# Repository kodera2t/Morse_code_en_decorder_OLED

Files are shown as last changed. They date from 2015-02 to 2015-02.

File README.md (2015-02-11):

# Morse_code_en_decorder_OLED
Morse code en decorder based on Arduino with OLED SPI display. Word per minutes is adjustable by rotary-encorder.
As a by-product project to my Tiny computer project, I made an stand-alone Tiny Morse code encoder/decorder. 
The procedure to make and program is almost same as previous one, 
http://hackaday.io/project/4201-really-tiny-computer-for-basic-bitlash-and-morse 
but the hardware is not same any more.

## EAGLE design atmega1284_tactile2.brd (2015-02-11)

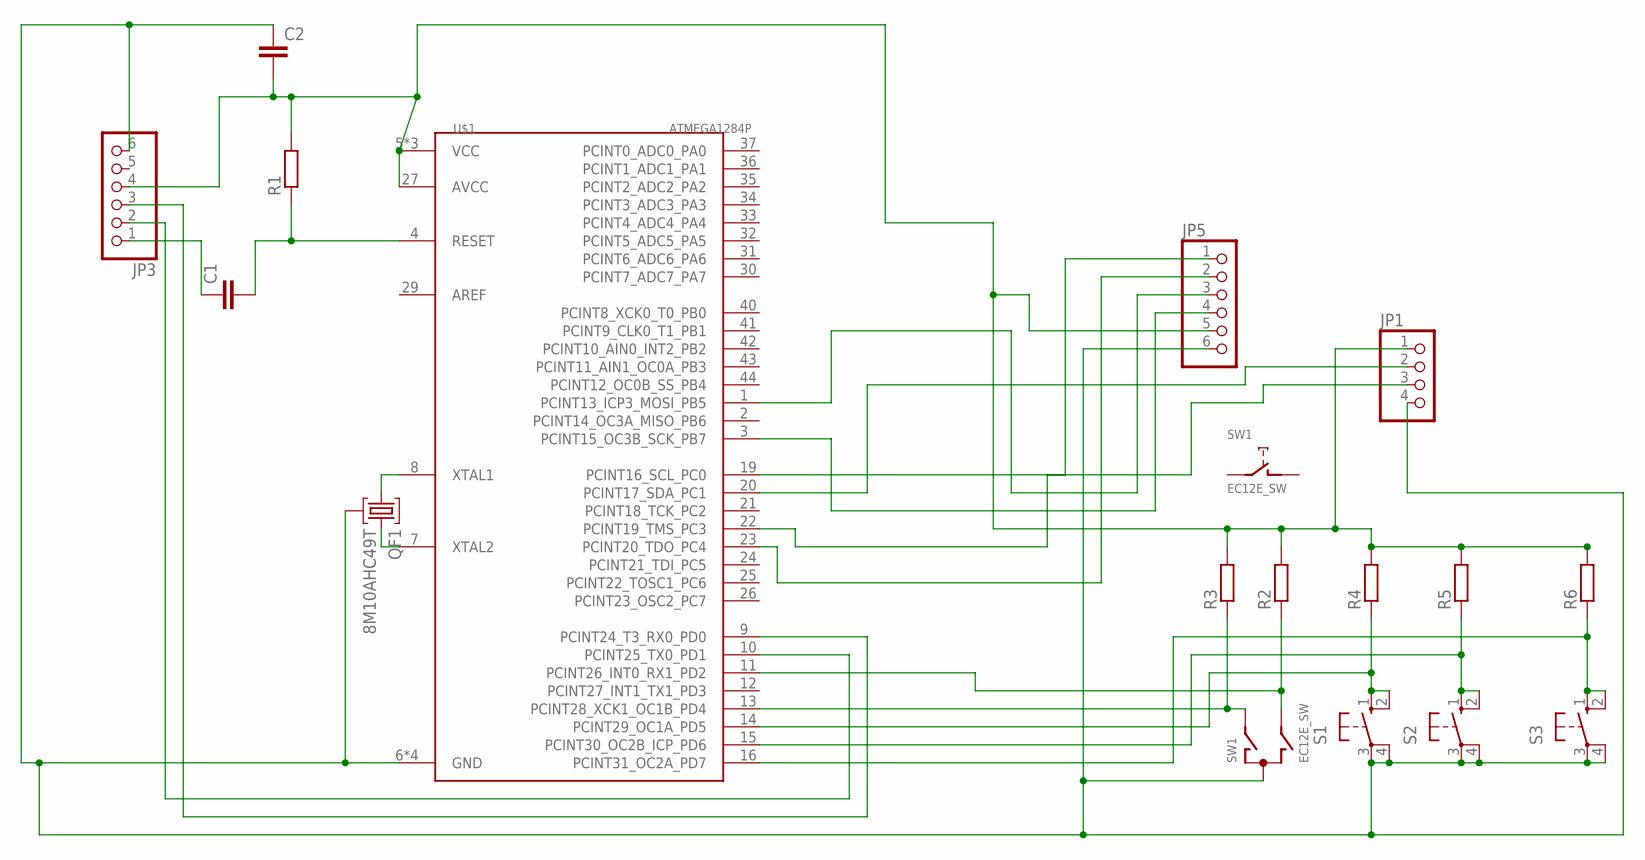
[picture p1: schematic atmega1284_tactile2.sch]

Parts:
C1, C2: C-EUC0805; C0805
JP1: PINHD-1X4; 1X04
JP3, JP5: PINHD-1X6; 1X06
QF1: 8M10AHC49T; HC49U
R1, R2, R3, R4, R5, R6: R-EU_R0805; R0805
S1, S2, S3: 10-XX; B3F-10XX
SW1: EC12E_SW; ALPS_EC12E_SW
U$1: ATMEGA1284P; TQFP44

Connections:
unnamed: JP5.3, U$1.1 (PCINT13_ICP3_MOSI_PB5)
unnamed: QF1.1, U$1.8 (XTAL1)
unnamed: QF1.3, U$1.7 (XTAL2)
unnamed: C2.1, JP1.4, JP3.6, JP5.6, QF1.2, S1.3, S1.4 (P1), S2.3, S2.4 (P1), S3.3, S3.4 (P1), SW1.C, U$1.6 (GND), U$1.18 (GND), U$1.28 (GND), U$1.39 (GND)
unnamed: JP5.4, U$1.3 (PCINT15_OC3B_SCK_PB7)
unnamed: R2.1, SW1.B, U$1.11 (PCINT26_INT0_RX1_PD2)
unnamed: C1.2, R1.1, U$1.4 (RESET)
unnamed: C1.1, JP3.1
unnamed: JP3.2, U$1.10 (PCINT25_TX0_PD1)
unnamed: JP3.3, U$1.9 (PCINT24_T3_RX0_PD0)
unnamed: JP5.1, U$1.22 (PCINT19_TMS_PC3)
unnamed: JP5.2, U$1.23 (PCINT20_TDO_PC4)
unnamed: R3.1, SW1.A, U$1.13 (PCINT28_XCK1_OC1B_PD4)
unnamed: R4.1, S1.1 (S), S1.2 (S1), U$1.14 (PCINT29_OC1A_PD5)
unnamed: R5.1, S2.1 (S), S2.2 (S1), U$1.15 (PCINT30_OC2B_ICP_PD6)
unnamed: R6.1, S3.1 (S), S3.2 (S1), U$1.16 (PCINT31_OC2A_PD7)
unnamed: C2.2, JP1.1, JP3.4, JP5.5, R1.2, R2.2, R3.2, R4.2, R5.2, R6.2, U$1.5 (VCC), U$1.17 (VCC), U$1.27 (AVCC), U$1.38 (VCC)
unnamed: JP1.2, U$1.20 (PCINT17_SDA_PC1)
unnamed: JP1.3, U$1.19 (PCINT16_SCL_PC0)

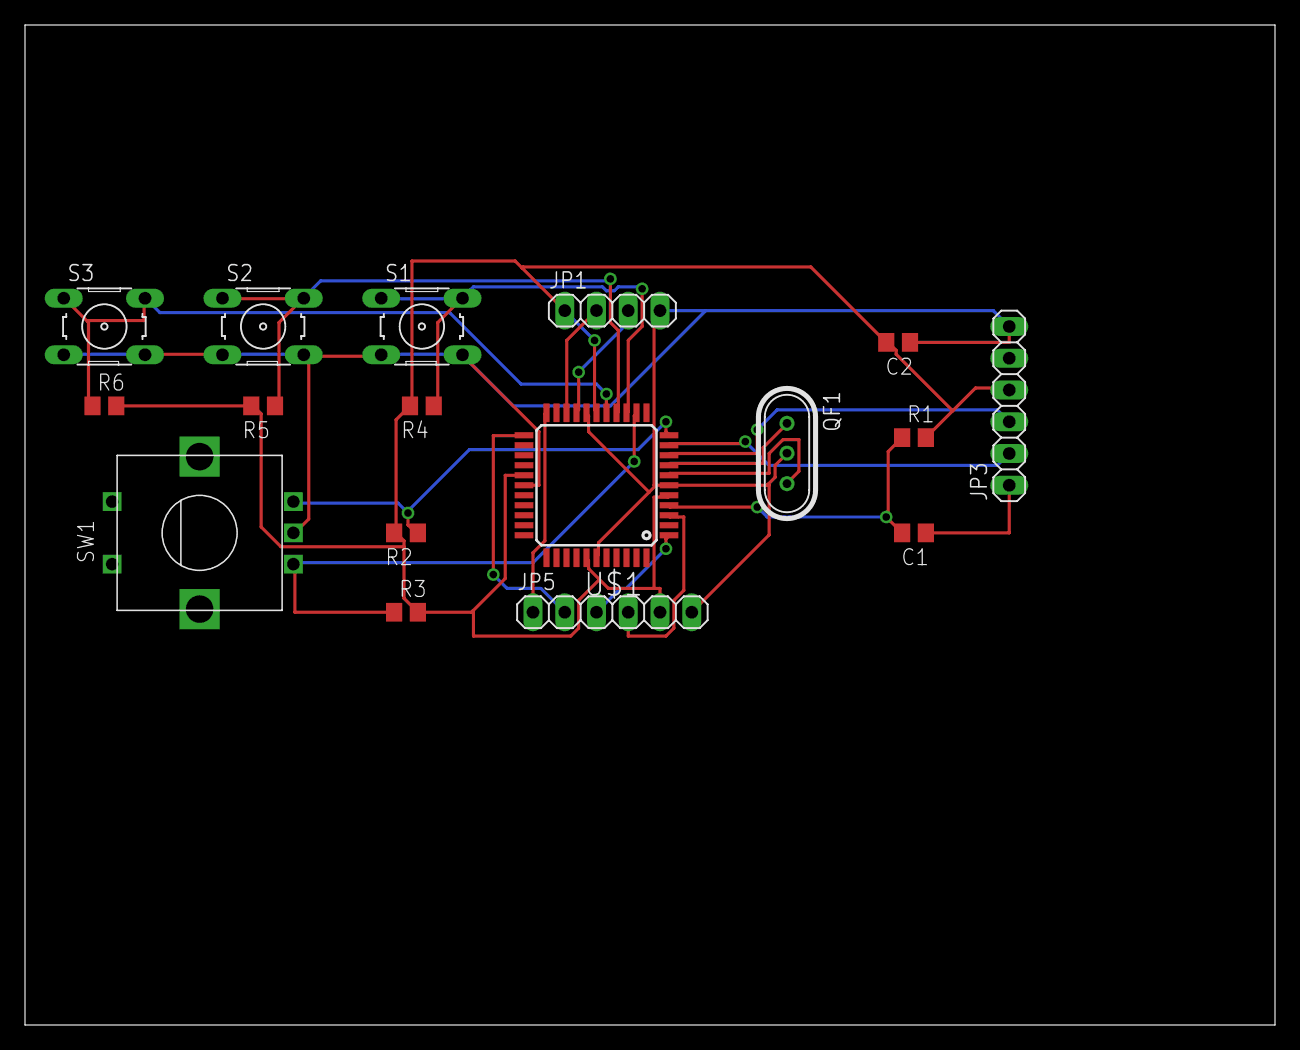
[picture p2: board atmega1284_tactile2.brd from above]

Board: 2 copper layers, 100.0 x 80.0 mm, 17 parts (0 on the bottom side), 19 nets.

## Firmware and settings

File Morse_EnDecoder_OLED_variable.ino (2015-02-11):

#include <avr/pgmspace.h>
#include <MorseEnDecoder.h>


//////////////// Newly added for graphic OLED(LCD) 128x64 support/////////////
#include <SPI.h>
#include <Wire.h>
#include <Adafruit_GFX.h>
#include <Adafruit_SSD1306.h>

// SPI PIN definition. Change to fit your board....
#define OLED_MOSI   5
#define OLED_CLK   7
#define OLED_DC    19
#define OLED_CS    18
#define OLED_RESET 20
Adafruit_SSD1306 display(OLED_MOSI, OLED_CLK, OLED_DC, OLED_RESET, OLED_CS);


int screenMem[147]; //the implementation of frame buffer is referenced from Ben Heck's
int cursorX = 0;    //Retro BASIC computer's source
int checkChar = 0;
int wpm = 13;

int terminal_1  = 10;
int terminal_2  = 12;
volatile char rot_state = 0;
volatile int encorder_val  = 0;
int event;

//////////////////////////////////////////////////////////////////////////////
////////////////////////////////////////////////////////////////////////////////
// ASCII Characters
#define CR	'\r'
#define NL	'\n'
#define LF      0x0a
#define TAB	'\t'
#define BELL	'\b'
#define SPACE   ' '
#define SQUOTE  '\''
#define DQUOTE  '\"'
#define CTRLC	0x1B  // Changed to ESC key (27 - 0x1B)
#define CTRLH	0x08
#define CTRLS	0x13
#define CTRLX	0x18

static const unsigned char initmsg[]          PROGMEM = "Morse EnDecoder";
static const unsigned char wpmsg[]              PROGMEM = "Current wpm is ";
static const unsigned char errormsg[]         PROGMEM = "< ERROR:too many morse signals! >";

// Pin mapping
const byte morseInPin = 14;      
const byte morseOutPin = 16;

// Instantiate Morse objects
morseDecoder morseInput(morseInPin, MORSE_KEYER, MORSE_ACTIVE_LOW);
morseEncoder morseOutput(morseOutPin);

void setup()
{
  Serial.begin(4800);
      display.begin();
    //   init done
    display.display();
    display.clearDisplay();
    display.setTextSize(1);
    display.setTextColor(WHITE);
    display.setCursor(0,0);
	for (int xg = 0 ; xg < 147 ; xg++) {
		screenMem[xg] = 32;
	}
 // setOutputHandler(&lcdChar);
  printmsg(initmsg);
  doFrame(126);

  printwpm(wpm);
  morseInput.setspeed(wpm);
  morseOutput.setspeed(wpm);
///// wpm setting ////////
//  attachInterrupt(0, Rotery_encorder, CHANGE);
  pinMode(terminal_1, INPUT);
  pinMode(terminal_2, INPUT);
  rot_state = rotary_getState(terminal_1, terminal_2);
//  digitalWrite(terminal_1, HIGH);
//  digitalWrite(terminal_2, HIGH);
//  attachInterrupt(1,mode_setting, CHANGE);
}


void loop()
{
  int old_wpm=wpm;
  char rot_past = rot_state;
  rot_state = rotary_getState(terminal_1, terminal_2);
  char rot_dir = rotary_getDir(rot_state, rot_past);
  switch(rot_dir){
    case 2:
      wpm=wpm+1;
      break;
    case 1:
      wpm=wpm-1;
      break;
  }
  if(old_wpm != wpm)
  {
  printwpm(wpm);
  morseInput.setspeed(wpm);
  morseOutput.setspeed(wpm);
		doFrame(126);
  }


  morseOutput.encode();
  // SEND MORSE (OUTPUT)
  // Encode and send text received from the serial port (serial monitor)
  if (morseOutput.available())
  {
    // Get character from serial and send as Morse code
    char sendMorse = Serial.read();
    morseOutput.write(sendMorse);
    //Serial.print(sendMorse);
    lcdChar(sendMorse);
  }

 morseInput.decode();
  // RECEIVE MORSE (INPUT)
  // If a character is decoded from the input, write it to serial port
  if (morseInput.available())
  {
    char receivedMorse = morseInput.read();
    lcdChar(receivedMorse);
   if(receivedMorse != 0xFF){
       Serial.print(receivedMorse);
    // A little error checking    
    if (receivedMorse == '#') printmsg(errormsg);
  }
  }
}

static void printwpm(int k)
{
                display.setCursor(0,0);
                display.print("      ");
 	        display.setCursor(30,0);
                display.print("wpm=");
		display.print(k); 
}

static void outchar(unsigned char c)
{
    lcdChar(c);
}

static void lcdChar(unsigned int c) {
if(c <= 128){
	if (c == 8) {	//Backspace?
	
		if (cursorX > 0) {
	
			cursorX -= 1;	
			screenMem[126 + cursorX] = 32;	
			doFrame(126 + cursorX); 
			
		}
	
	}

	if (c != 13 and c != 10 and c != 8) {	
	
		screenMem[126 + cursorX] = c;
		cursorX += 1;
		if (cursorX < 21) {
	        display.setCursor(cursorX*6,8*7);		
		display.write(c);
		display.display();
		}
		
	}
	
	if (cursorX == 21 or c == 10) {			
	
		for (int xg = 21 ; xg > 0 ; xg--) {

			screenMem[0 + xg] = screenMem[21 + xg];
			screenMem[21 + xg] = screenMem[42 + xg];		
			screenMem[42 + xg] = screenMem[63 + xg];
			screenMem[63 + xg] = screenMem[84 + xg];
			screenMem[84 + xg] = screenMem[125 + xg];		
//			screenMem[125 + xg] = screenMem[146 + xg];



//			screenMem[146 + xg] = 32;
		
		        screenMem[125 + xg] = 32;
		}
	
		cursorX = 0;
		
		doFrame(125);	
                printwpm(wpm);

	}


}
}

static void doFrame(byte amount) {
        int xposi,yposi,yshift;
        display.clearDisplay();
	for (int xg = 0 ; xg < amount ; xg++) {
                yshift=int(xg/21.0);
                yposi=yshift*8;
                xposi=(xg-yshift*21)*6;
	        display.setCursor(xposi,yposi+10);
		display.write(screenMem[xg]);
	}
        display.display();
  printwpm(wpm);
}  

/***************************************************************************/
void printmsgNoNL(const unsigned char *msg)
{
  while( pgm_read_byte( msg ) != 0 ) {
    outchar( pgm_read_byte( msg++ ) );
  };
}

/***************************************************************************/
void printmsg(const unsigned char *msg)
{
  printmsgNoNL(msg);
  line_terminator();
}

static void line_terminator(void)
{
  outchar(NL);
  outchar(CR);
}


char rotary_getState(char terminal_1, char terminal_2){
  if(digitalRead(terminal_1)){
    if(digitalRead(terminal_2)) return 2;
    else return 0;
  }
  else{
    if(digitalRead(terminal_2)) return 1;
    else return 3;
  }
}

char rotary_getDir(int state, int past_state){
  if((state+3+1)%3 == past_state) return 1;
  else if((state+3-1)%3 == past_state) return 2;
  return 0;
}
